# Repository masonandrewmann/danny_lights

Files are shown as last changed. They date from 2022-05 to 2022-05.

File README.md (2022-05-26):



# the cyberbar - wifi artnet/dmx + IR led lighting fixtures 
using ESP8266 for individually addressable LED bars controllable through both IR remote and wifi Artnet network

example

## User Guide!
Hello and welcome to the *magical* light fixtures that can be controlled via a handy 44 key infrared remote OR from a lighting console, computer, or mobile device via DMX lighting protocol. This is a walkthrough of how to use the lights. 

### IR remote mode

Put switch in IR position and use your 44 key remote! Here is what it does:
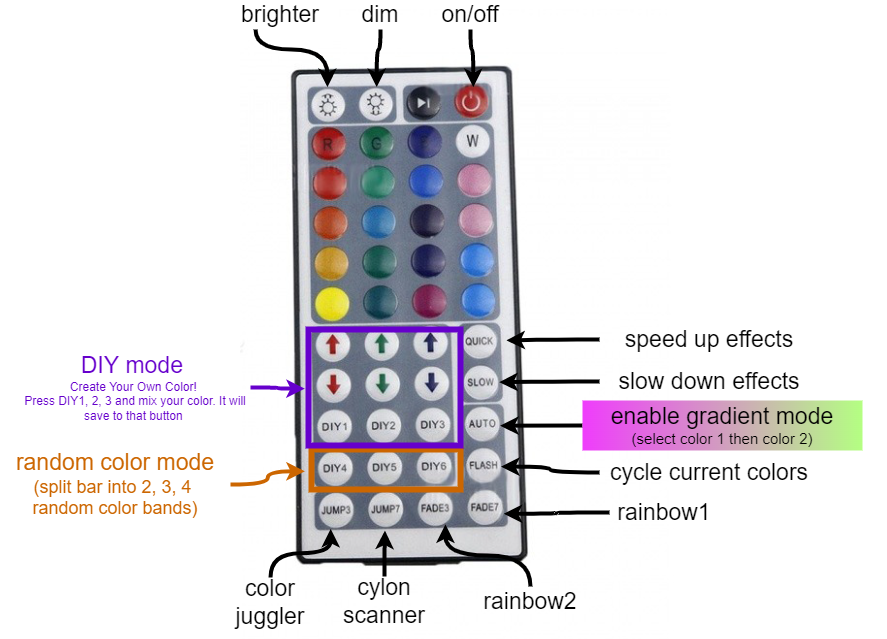
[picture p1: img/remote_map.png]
remote

### Wifi Artnet/DMX mode
#### WIFI setup 
  - put switch in DMX position
  - It will initially be in "Access Point" mode. Connect to the device as you would connect to a new wifi router. It will be called 'Cyberbar' initially in your wifi setup. 
    - username: CyberBar1 (or 2 or 3)
    - password: password
  - Once you are connected to it, you should be taken to IP address **192.168.4.1** in your browswer. The screen should look like this: 

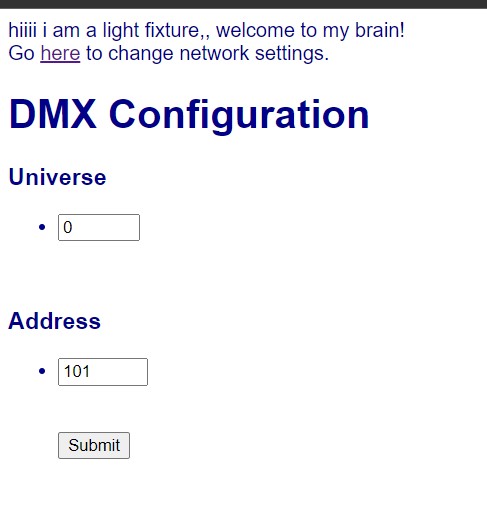
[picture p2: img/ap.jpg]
access
   
  - ArtNet typically starts at Universe 0! Check your console/lighting program for what universe you start at. 
  - Set the DMX address. 
  - If you want to connect multiple fixtures together, or use this in conjunction with something else, click the link to change the wifi settings. The page will look like this:
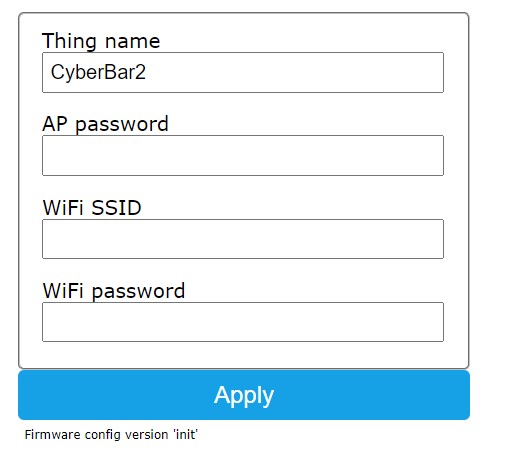
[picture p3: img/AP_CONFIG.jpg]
network
  
  - you can change the name of the fixture, and connect to another wifi network using its SSID and Password. This way you can connect many fixutres on the same network, or connect the fixture to the internet to control remotely.  
  - **reset button:** hold while turning on to reset the WIFI network to access point mode. 
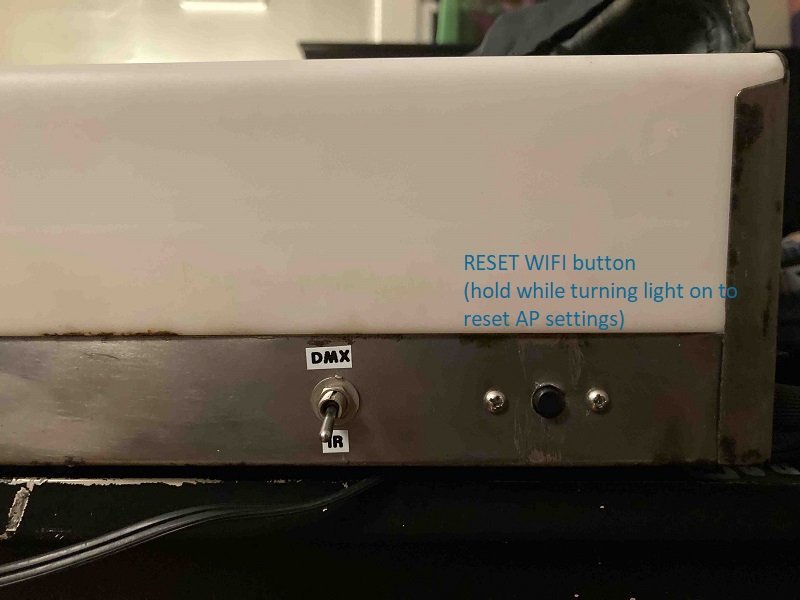
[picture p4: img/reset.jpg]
reset
 

#### DMX settings
  - set as 3 channel fixtures with 32 pixels in each fixture ([example setup shown here](https://htmlpreview.github.io/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))
    - color mode = RGB

behold the beauty!
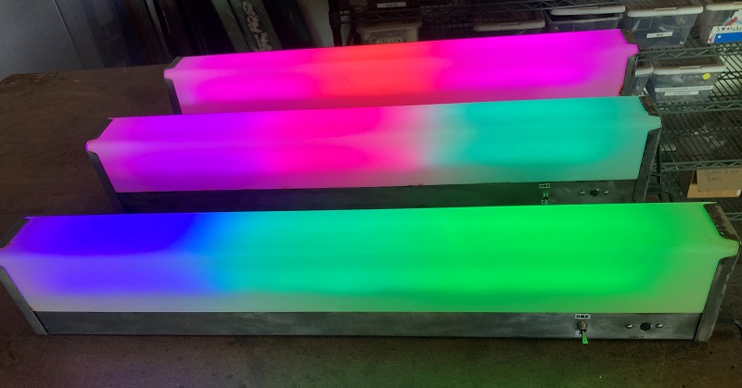
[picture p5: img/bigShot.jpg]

## installation guide for setting up your own:
I am assuming you are using the classic Arduino IDE!
 
IR code was modifed from [dmonty2's wonderful repo](https://github.com/dmonty2/ir_remote_leds)

make sure you install ESP8266 board add-ons for the IDE, [here](https://randomnerdtutorials.com/how-to-install-esp8266-board-arduino-ide/) is instructions on how to do that 

Only tested with ESP8266 using "NodMCU 1.0 (ESP-12E Module)" as the board. 

### required libraries: 
IOT and WIFI stuff: 
 - [IOTWebConf.h](https://github.com/prampec/IotWebConf) // NOTE: This library has been modified so that it stores in EEPROM starting at address 8 instead of 0, use the version included in this repository rather than the official release OR change the line "# define IOTWEBCONF_CONFIG_START 0" to "# define IOTWEBCONF_CONFIG_START 8" in IotWebConf.h in the official release. **The updated file is in library/IotWebConf.h. Move this into your Arduino library folder!**
- [ArtnetWifi.h ](https://github.com/natcl/Artnet) - not to be confused with other artnet wifi libraries,  this is the one to use

LED stuff: 
- [Adafruit_NeoPixel.h](https://github.com/adafruit/Adafruit_NeoPixel)
- [FastLED](https://github.com/FastLED/FastLED)
  
Infrared (IR) reciever stuff: 
- [IRRemoteESP8266](https://github.com/crankyoldgit/IRremoteESP8266)
-  [IRremote](https://github.com/NicoHood/IRLremote)  (outdated?)

Misc Libraries to include: 
- EEPROM.h , should be inheirited from the ESP8266 board library 

### hardware notes
Here are the interals: 
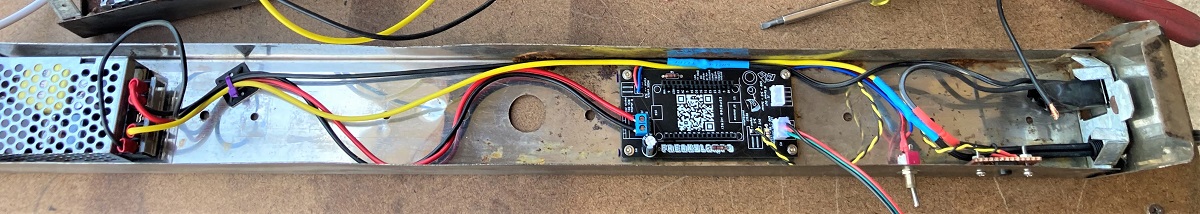
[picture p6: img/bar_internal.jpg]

Here is the schematic: 
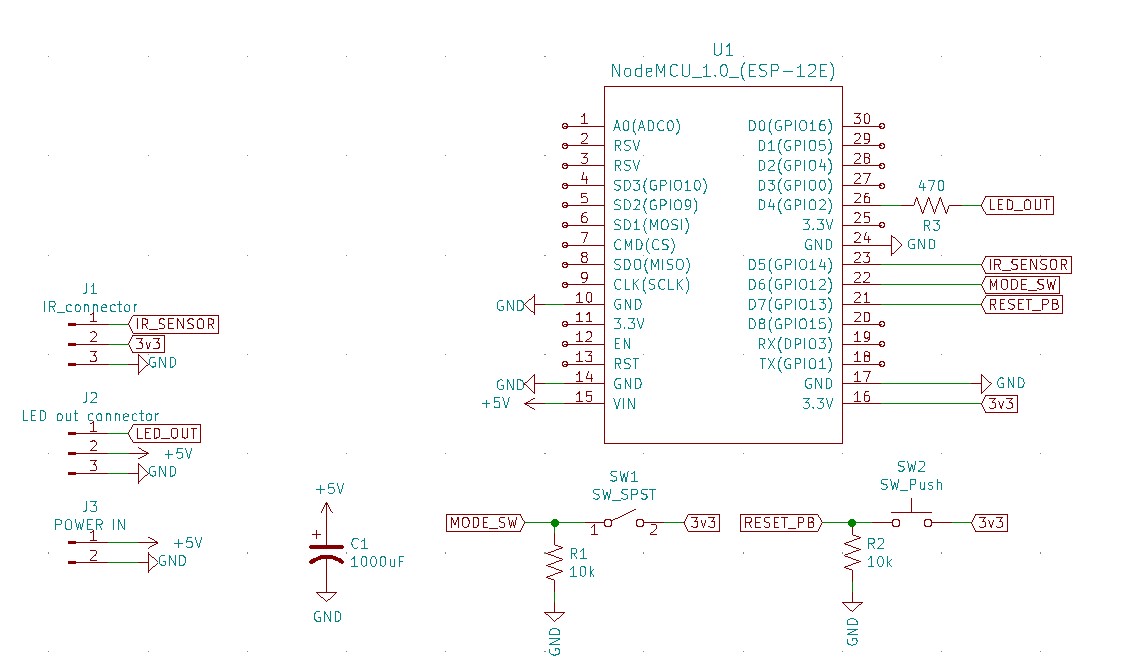
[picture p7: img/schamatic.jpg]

Included in the repo is a KiCad file for a PCB for the ESP8266:
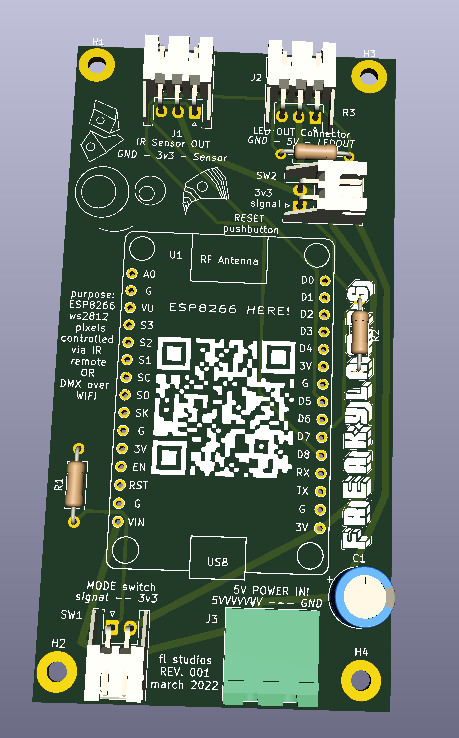
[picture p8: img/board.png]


## pinout for esp8266

LEDPIN          16 // D0    (built in indicator)

BUTTONPIN       13 // D7    (reset button)

MODEPIN         12 // D6    (dmx or IR)

ir recieiver =  14 // D5

led output     2 // D4      (addressable led output)

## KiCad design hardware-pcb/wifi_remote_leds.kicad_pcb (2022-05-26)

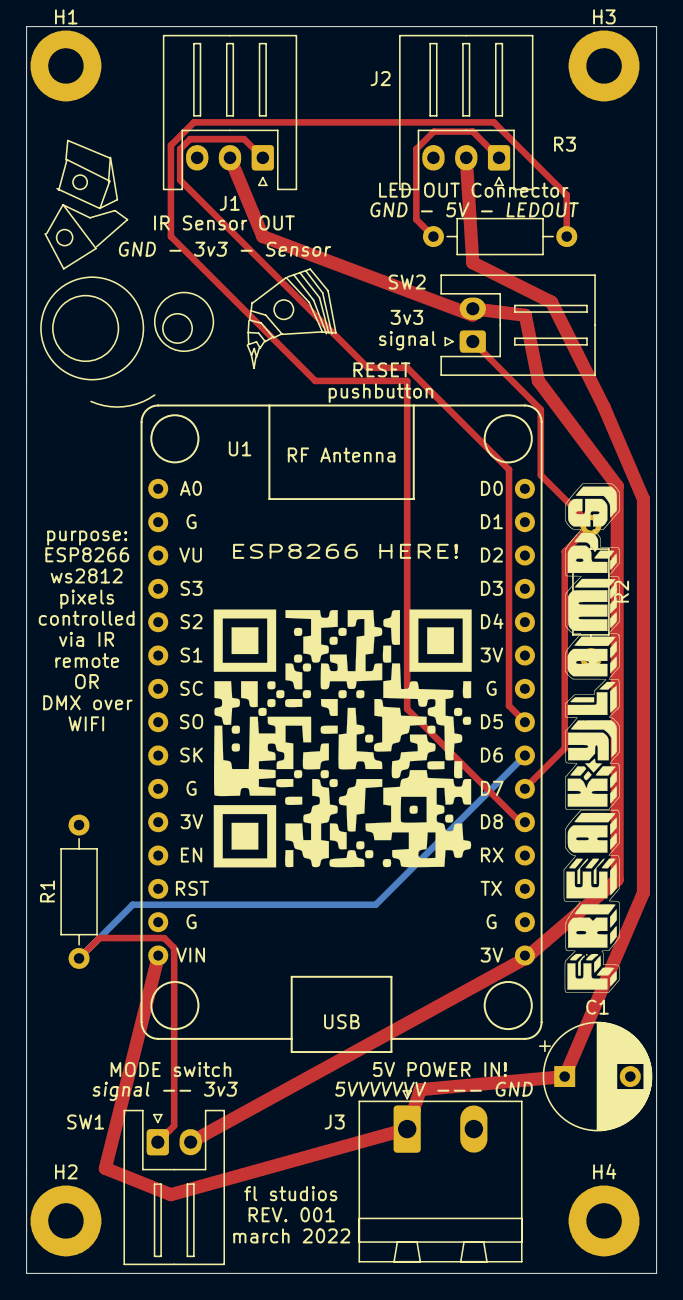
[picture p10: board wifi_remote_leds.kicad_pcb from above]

Board: 2 copper layers, 48.0 x 95.0 mm, 14 parts (0 on the bottom side), 8 nets.

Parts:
C1: 1000uF; CP_Radial_D8.0mm_P5.00mm
H1, H2, H3, H4: MountingHole; MountingHole_2.7mm_M2.5_Pad
J1: IR_connector; JST_XH_S3B-XH-A_1x03_P2.50mm_Horizontal
J2: LED out connector; JST_XH_S3B-XH-A_1x03_P2.50mm_Horizontal
J3: POWER IN; PhoenixContact_MSTBA_2,5_2-G-5,08_1x02_P5.08mm_Horizontal
R1, R2: 10k; R_Axial_DIN0207_L6.3mm_D2.5mm_P10.16mm_Horizontal
R3: 470; R_Axial_DIN0207_L6.3mm_D2.5mm_P10.16mm_Horizontal
SW1: SW_SPST; JST_XH_S2B-XH-A_1x02_P2.50mm_Horizontal
SW2: SW_Push; JST_XH_S2B-XH-A_1x02_P2.50mm_Horizontal
U1: NodeMCU_1.0_(ESP-12E); NodeMCU1.0(12-E)

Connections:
3v3: J1.2, SW1.2, SW2.2, U1.16
+5V: C1.1, J2.2, J3.1, U1.15
GND: C1.2, J1.3, J2.3, J3.2, R1.2, R2.2, U1.10, U1.14, U1.17, U1.24
IR_SENSOR: J1.1, U1.23
LED_OUT: J2.1, R3.1
MODE_SW: R1.1, SW1.1, U1.22
unnamed: R3.2, U1.20
RESET_PB: R2.1, SW2.1, U1.21

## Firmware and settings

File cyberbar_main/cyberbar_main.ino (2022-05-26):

/*
  FastLED + standard 44 Key Ir RGB Led remote + Teensy 3.2
 MMason Mann 3.2.2021
  Adapted from Dean Montgomery --- 44-key IR remote customization
  https://github.com/dmonty2/ir_remote_leds
*/

// south river wifi: RT-AC66U_B1_40_2G

//from wifi config code
#include <EEPROM.h>
#include <IotWebConf.h>
#include <ArtnetWifi.h> // https://github.com/natcl/Artnet  
#include <Adafruit_NeoPixel.h>
#define FASTLED_ESP8266_RAW_PIN_ORDER
#include <FastLED.h>
#include <IRremoteESP8266.h>
#include <IRrecv.h>
#include <IRutils.h>

#define IR_TOLERANCE 8
#define LEDPIN 16 //built in
#define BUTTONPIN 13 // D7 on esp8266 dev boad
#define MODEPIN 12 // D6 on esp8266 dev board

///EEPROM STRUCTURE
//0 -- effect number
//1 -- color for solid color
//4 -- color 1 for gradient
//7 -- color 2 for gradient
//10 --- number of bands for randomBands
//13 --- brightness
//16 DIY1 Color
//19 DIY2 Color
//22 DIY3 Color
//25 -- DMX Universe Number
//30 -- DMX Starting Address Number
//35 -- IOT Library Stuff

//EEPROM addresses
int addr_universeNum = 25;
int addr_dmxAdr = 30;

int universeNum;
int dmxAdr;

// -- Initial name of the Thing. Used e.g. as SSID of the own Access Point.
const char thingName[] = "CyberBar1";

// -- Initial password to connect to the Thing, when it creates an own Access Point.
const char wifiInitialApPassword[] = "password";

DNSServer dnsServer;
WebServer server(80);

IotWebConf iotWebConf(thingName, &dnsServer, &server, wifiInitialApPassword);

int status = WL_IDLE_STATUS;

// Artnet settings
ArtnetWifi artnet;

// An IR detector/demodulator is connected to GPIO pin 14(D5 on a NodeMCU
// board).
// Note: GPIO 16 won't work on the ESP8266 as it does not have interrupts.
const uint16_t kRecvPin = 14;

IRrecv irrecv(kRecvPin);

decode_results signals;

uint32_t IRCommand;
boolean haveWePickedColors;

//LED setup
#define DATA_PIN    2 // D4 on ESP8266
#define LED_TYPE    WS2812B
#define COLOR_ORDER GRB
#define NUM_LEDS    32
#define BRIGHTNESS          200   // GLOBAL brightness scale

CRGB leds[NUM_LEDS];
CRGB ledColors[NUM_LEDS];
CHSV color;
CHSV color1;
CHSV color2;
boolean powerOn = true;
enum Rgb { RED, GREEN, BLUE };

//other variables setups

int colorIndex;
#define MIN_intrvl 10  // fastest the led libraries can update without loosing access to PIR remote sensing.
long    intrvl = 40;
unsigned long currentMillis = millis(); // define here so it does not redefine in the loop.
unsigned long previousMillis = 0;
uint8_t effect = 0;
uint8_t h = 0; //hue
uint8_t s = 255; //saturation
uint8_t v = 255; //value
uint8_t brightnessFactor = 20 ; // how many steps to from full bright to black out
uint8_t brightnessInterval = BRIGHTNESS / brightnessFactor ; /// BRIGHTNESS (overall brighntess// max brigtness) divided by btightness factor creates the interval you step by
uint8_t brightness = BRIGHTNESS; // this is new brightness ( BRIGHTNESS - the brightness factor)
uint8_t bands;
boolean initialized = false;

#define SOLIDCOLOR 1
#define GRADIENT 2
#define RANDOMBANDS 3
#define FADE7 4
#define FADE3 5
#define SINELON 6
#define JUGGLE 7
#define BARBERPOLE 8
#define BRIGHT 9
#define DIM 10
#define BARBERPOLE1 11
#define BARBERPOLE2 12
#define EASTEREGGPOLE 13

uint8_t randNumber1;
uint8_t randNumber2;
uint8_t randNumber3;

struct buttonNames {
  uint32_t bright;   uint32_t dim;        uint32_t ppause;     uint32_t power;
  uint32_t red1;     uint32_t green1;     uint32_t blue1;      uint32_t white1;
  uint32_t red2;     uint32_t green2;     uint32_t blue2;      uint32_t white2;
  uint32_t red3;     uint32_t green3;     uint32_t blue3;      uint32_t white3;
  uint32_t red4;     uint32_t green4;     uint32_t blue4;      uint32_t white4;
  uint32_t red5;     uint32_t green5;     uint32_t blue5;      uint32_t white5;
  uint32_t red_up;   uint32_t green_up;   uint32_t blue_up;    uint32_t quick;
  uint32_t red_down; uint32_t green_down; uint32_t blue_down;  uint32_t slow;
  uint32_t diy1;     uint32_t diy2;       uint32_t diy3;       uint32_t autom;
  uint32_t diy4;     uint32_t diy5;       uint32_t diy6;       uint32_t flash;
  uint32_t jump3;    uint32_t jump7;      uint32_t fade3;      uint32_t fade7;
};

//// These are the codes for my remote
const buttonNames remote =  {
  0xFF3AC5,   0xFFBA45,   0xFF827D,   0xFF02FD,
  0xFF1AE5,   0xFF9A65,   0xFFA25D,   0xFF22DD,
  0xFF2AD5,   0xFFAA55,   0xFF926D,   0xFF12ED,
  0xFF0AF5,   0xFF8A75,   0xFFB24D,   0xFF32CD,
  0xFF38C7,   0xFFB847,   0xFF7887,   0xFFF807,
  0xFF18E7,   0xFF9867,   0xFF58A7,   0xFFD827,
  0xFF28D7,   0xFFA857,   0xFF6897,   0xFFE817,
  0xFF08F7,   0xFF8877,   0xFF48B7,   0xFFC837,
  0xFF30CF,   0xFFB04F,   0xFF708F,   0xFFF00F,
  0xFF10EF,   0xFF906F,   0xFF50AF,   0xFFD02F,
  0xFF20DF,   0xFFA05F,   0xFF609F,   0xFFE01F,
};

uint32_t commandsArray[] =  {
  0xFF3AC5,   0xFFBA45,   0xFF827D,   0xFF02FD,
  0xFF1AE5,   0xFF9A65,   0xFFA25D,   0xFF22DD,
  0xFF2AD5,   0xFFAA55,   0xFF926D,   0xFF12ED,
  0xFF0AF5,   0xFF8A75,   0xFFB24D,   0xFF32CD,
  0xFF38C7,   0xFFB847,   0xFF7887,   0xFFF807,
  0xFF18E7,   0xFF9867,   0xFF58A7,   0xFFD827,
  0xFF28D7,   0xFFA857,   0xFF6897,   0xFFE817,
  0xFF08F7,   0xFF8877,   0xFF48B7,   0xFFC837,
  0xFF30CF,   0xFFB04F,   0xFF708F,   0xFFF00F,
  0xFF10EF,   0xFF906F,   0xFF50AF,   0xFFD02F,
  0xFF20DF,   0xFFA05F,   0xFF609F,   0xFFE01F,
};

CHSV r1 (0, 255, 255);
CHSV g1 (96, 255, 255);
CHSV b1 (160, 255, 255);
CHSV w1 (4, 10, 255);
CHSV r2 (16, 255, 255);
CHSV g2 (112, 255, 255);
CHSV b2 (176, 255, 255);
CHSV w2  (52, 200, 255);
CHSV r3 (32, 255, 255);
CHSV g3 (120, 255, 255);
CHSV b3 (192, 255, 255);
CHSV w3 (45, 200, 255);
CHSV r4 (48, 255, 255);
CHSV g4 (128, 255, 255);
CHSV b4 (208, 255, 255);
CHSV w4 (96, 70, 255);
CHSV r5 (60, 255, 255);
CHSV g5 (136, 255, 255);
CHSV b5 (224, 255, 255);
CHSV w5 (64, 60, 255);

// CHSV Color Array

CHSV CHSV_array[] = { r1, g1, b1, w1,
                      r2, g2, b2, w2,
                      r3, g3, b3, w3,
                      r4, g4, b4, w4,
                      r5, g5, b5, w5
                    };

                    // storing diy in eeprom

uint8_t r = 0; //red
uint8_t g = 0; //green
uint8_t b = 0; //blue
#define SLIDE_VALUE 110
#define SLIDE_RGB 111
uint8_t slide = SLIDE_VALUE;
uint8_t last_white = 0;
CHSV water[NUM_LEDS];

struct DIY {
  uint8_t r; uint8_t g; uint8_t b;
};
//Track start points in eeprom index
static uint16_t eeprom_addr[] = {16, 19, 22};

struct DIY_BUTTON {
  uint8_t button;
  bool dirty;
};
DIY_BUTTON lastdiy = { 0, false };
/*
struct DIYSTORE {
  DIY diy1; DIY diy2; DIY diy3; // stored at 0,  3,  6
  DIY diy4; DIY diy5; DIY diy6; // stored at 9, 12, 15
};
 size of EEPROM: 1024 bytes
 size of 44 key remote: 176 bytes
 size of DIY: 3 bytes
 size of DIYSTORE: 18 bytes
 */

void setup() {
  //------------------------SETUP FOR ARTNET MODE------------------------
  Serial.begin ( 115200 );
     while (!Serial)  // Wait for the serial connection to be establised.
    delay(50);
  Serial.println("Setup begin");
  EEPROM.begin(512);
  pinMode(MODEPIN, INPUT);
  
  artnet.begin();
  artnet.setArtDmxCallback(onDmxFrame);
  
  //read eeprom to set global DMX configuration variables
  universeNum = readIntFromEEPROM(addr_universeNum);
  dmxAdr = readIntFromEEPROM(addr_dmxAdr);
  Serial.println("Universe Num from EEPROM: ");
  Serial.println(universeNum);
  Serial.println("Starting Address from EEPROM:");
  Serial.println(dmxAdr);
  Serial.println("iot eeprom start ");
  Serial.println(IOTWEBCONF_CONFIG_START);

  // ACCESS POINT CONFIG
    // -- Initializing the configuration.
    pinMode(BUTTONPIN, INPUT);
  if (digitalRead(BUTTONPIN) == 0){
    Serial.println("Skipping Access Point Setup Mode");
    iotWebConf.skipApStartup();
  } else {
    Serial.println("Entering Access Point Setup Mode");
  }
  iotWebConf.init();
  iotWebConf.setStatusPin(LEDPIN);
  pinMode(LEDPIN, OUTPUT);

  // -- Set up required URL handlers on the web server.
  server.on("/", handleRoot);
  server.on ( "/submit", handleSubmit );
  server.on("/config", []{ iotWebConf.handleConfig(); });
  server.onNotFound([](){ iotWebConf.handleNotFound(); });

  Serial.println("Ready.");

  //------------------------setup for IR remote mode------------------------
  irrecv.enableIRIn();  // Start the receiver
  Serial.println();
  Serial.print("IRrecvDemo is now running and waiting for IR message on Pin ");
  Serial.println(kRecvPin);
  
//  pinMode(13, OUTPUT);
//  digitalWrite(13, HIGH);   // turn the LED on (HIGH is the voltage level)

  randomSeed(analogRead(0));
  // In case the interrupt driver crashes on setup, give a clue
  // to the user what's going on.
  Serial.println("Enabling IRin");
  irrecv.enableIRIn(); // Start the receiver
  Serial.println("Enabled IRin");
  FastLED.addLeds<LED_TYPE, DATA_PIN, COLOR_ORDER>(leds, NUM_LEDS).setCorrection(TypicalLEDStrip);
  // set master BRIGHTNESS control
  FastLED.setBrightness(BRIGHTNESS);
  FastLED.clear();  // clear all pixel data
  FastLED.show();

  startFromEEPROM();
//  EEPROM.get(0, effect); // get that effect number
//  Serial.print("EEPROM loading-- ");
//  Serial.println(effect);
//  
//  if (effect == SOLIDCOLOR) {
//    EEPROM.get(1, color);
//    solidColor(color);
//  }
//  if (effect == GRADIENT) {
//    EEPROM.get(4, color1);
//    EEPROM.get(7, color2);
//    fill_gradient(leds, 0, color1, NUM_LEDS, color2, SHORTEST_HUES);
//    FastLED.show();
//  }
//  if (effect == RANDOMBANDS) {
//    EEPROM.get(10, bands);
//    randomBands(bands);
//  }
}

void loop() {
  int tempMode = digitalRead(MODEPIN); //read switch to move between Art-Net mode and IR mode
  if (tempMode == 1){
  // Art-Net Mode
    iotWebConf.doLoop();  
    artnet.read();
    if (initialized){
      initialized = false;
    }
  } 
  
  else {
    if (!initialized){
      startFromEEPROM();
    }
  currentMillis = millis();
  if (!irrecv.decode(&signals)) {
    if (currentMillis - previousMillis > intrvl) {
      previousMillis = currentMillis;
      update_effect();
      FastLED.show();
    }
  }
  if (irrecv.decode(&signals)) {
    // print() & println() can't handle printing long longs. (uint64_t)
    mainButton();
    serialPrintUint64(signals.value, HEX);
    Serial.println("");
    irrecv.resume();  // Receive the next value
  }
  delay(100);
  }
}

String getPage(){
  String s = "<!DOCTYPE html><html lang=\"en\"><head><meta name=\"viewport\" content=\"width=device-width, initial-scale=1, user-scalable=no\"/>";
  s += "<title>IotWebConf 01 Minimal</title></head><body>hiiii i am a light fixture,, welcome to my brain!<br>";
  s += "Go <a href='config'>here</a> to change network settings.";
  s += "<title>Light Bar</title>";
  s += "<style> body { background-color: #fffff; font-family: Arial, Helvetica, Sans-Serif; Color: #000088; }</style>";
  s += "</head><body><h1>DMX Configuration</h1>";
  s += "<h3>Universe</h3>";
  s += "<form action='/submit' method='POST'>";
  s += "<ul><li><input type='number' name='Uni' id='Uni' value='" + String(universeNum) + "' min='0' max='24'>";
  s += "</li></ul>";
  s += "<br>";
  s += "<h3>Address</h3>";
  s += "<form action='submit' method='POST'>";
  s += "<ul><li><input type='number' name='Adr' id = 'Adr' value ='" + String(dmxAdr) + "' min='0' max='512'>";
  s += "<br><br><br>";
  s += "<input type = 'submit' value='Submit'></li></ul>";
  s += "</body></html>\n";
  return s;
}

void writeIntIntoEEPROM(int address, int number)
{ 
  EEPROM.write(address, (number >> 24) & 0xFF);
  EEPROM.write(address + 1, (number >> 16) & 0xFF);
  EEPROM.write(address + 2, (number >> 8) & 0xFF);
  EEPROM.write(address + 3, number & 0xFF);
  EEPROM.commit();  
}

int readIntFromEEPROM(int address)
{
  return ((int)EEPROM.read(address) << 24) +
         ((int)EEPROM.read(address + 1) << 16) +
         ((int)EEPROM.read(address + 2) << 8) +
         (int)EEPROM.read(address + 3);
}
 
void handleSubmit(){

  Serial.println ("handleSubmit");
  //fetch DMX configuration
    String universeNumStr = server.arg(0);
    String dmxAdrStr = server.arg(1);
  //convert DMX configuration to ints
    universeNum = universeNumStr.toInt();
    dmxAdr = dmxAdrStr.toInt();
  //annnnd write it into EEPROM
    writeIntIntoEEPROM(addr_universeNum, universeNum);
    writeIntIntoEEPROM(addr_dmxAdr, dmxAdr);
    if (EEPROM.commit()) {
      Serial.println("EEPROM successfully committed");
    } else {
      Serial.println("ERROR! EEPROM commit failed");
    }
   
  String
  message = "URI: ";
  message += server.uri();
  message += "\nMethod: ";
  message += (server.method() == HTTP_GET)?"GET":"POST";
  message += "\nArguments: ";
  message += server.args();
  message += "\n";
  for (uint8_t i=0; i<server.args(); i++){
    message += " " + server.argName(i) + ": " + server.arg(i) + "\n";
  }
  Serial.println(message);
  Serial.println("Universe Number:");
  Serial.println(universeNum);
  Serial.println("DMX Address:");
  Serial.println(dmxAdr);
  server.send ( 200, "text/html", getPage() );
}

/**
 * Handle web requests to "/" path.
 */
void handleRoot()
{
  // -- Let IotWebConf test and handle captive portal requests.
  if (iotWebConf.handleCaptivePortal())
  {
    // -- Captive portal request were already served.
    return;
  }
  String s = getPage();
  server.send(200, "text/html", s);
}

void onDmxFrame(uint16_t universe, uint16_t length_, uint8_t sequence, uint8_t* data)
{
  int universeFromEEPROM = readIntFromEEPROM(addr_universeNum);
  int startAddressFromEEPROM = readIntFromEEPROM(addr_dmxAdr);
//  Serial.println("-----FRAME RECIEVED-------");
//  Serial.println(universe);
//  Serial.println(universeFromEEPROM);
//  Serial.println(startAddressFromEEPROM);
//  Serial.println(length_);

    if (universe == universeFromEEPROM){
//      Serial.println("correct Universe");
    for (int i = 0; i < NUM_LEDS; i++)
    {
//      Serial.println(i);
        leds[i].setRGB(
          data[startAddressFromEEPROM + i * 3 - 1],
          data[startAddressFromEEPROM + i * 3],
          data[startAddressFromEEPROM + i * 3 + 1]
          );
    }
  }
//  Serial.println("Done printing frame");   
    FastLED.show();
}

void mainButton() {
//  IRCommand = getButton();
  IRCommand = signals.value;
  if (IRCommand == remote.power) {
//    FastLED.clear();  // clear all pixel data
//    FastLED.show();
//    effect = 0; //ot to reset the effect counter so we dont go into the  effects loop
//    Serial.println("power");
//    startFromEEPROM();
    if (powerOn){
      FastLED.setBrightness(brightness);
    } else {
      FastLED.setBrightness(0);
    }
    powerOn = !powerOn;
  }

  //definitions for just solid colors
  if ( IRCommand == remote.red1 || IRCommand == remote.green1 || IRCommand == remote.blue1 || IRCommand == remote.white1 ||
       IRCommand == remote.red2 || IRCommand == remote.green2 || IRCommand == remote.blue2 || IRCommand == remote.white2 ||
       IRCommand == remote.red3 || IRCommand == remote.green3 || IRCommand == remote.blue3 || IRCommand == remote.white3 ||
       IRCommand == remote.red4 || IRCommand == remote.green4 || IRCommand == remote.blue4 || IRCommand == remote.white4 ||
       IRCommand == remote.red5 || IRCommand == remote.green5 || IRCommand == remote.blue5 || IRCommand == remote.white5 ) {
    for (int i = 4; i < 24; i++) { //the first 4 buttons are not color buttons, so we dont wanna scan through those in the array
//      Serial.println("buttonNum: " + i);
      if (IRCommand == commandsArray[i]) {
        colorIndex = i - 4;
        Serial.print("THE color index is: ");
        Serial.println(i);
      }
    }
    CHSV color =  CHSV_array[colorIndex];
    effect = SOLIDCOLOR;
    solidColor(color);
    //nscale8_video(brightness); // dim to max brightness
    FastLED.show();

    EEPROM.put(0, effect); // Eeprom address 0 is effect/mode
    EEPROM.put(1, color); // eeprom address 1,2,3 are color1
    EEPROM.commit();  
      Serial.println("solid_colors");
  }

  if (IRCommand == remote.autom) {
    FastLED.clear();  // clear all pixel data
    FastLED.show();
    staticGradient();
    IRCommand = 0x00000000;
    haveWePickedColors = false;
    effect = GRADIENT; // got to reset the effect counter so we dont go into the  effects loop
    EEPROM.put(0, effect);
    EEPROM.commit();  
      Serial.println("autom");
  }

  if (IRCommand == remote.jump3) {
    // stage = 1;
    intrvl = 65;
    h = 0; s = 255; v = 0;
    effect = JUGGLE;
    EEPROM.put(0, effect);
    EEPROM.commit();  
      Serial.println("jump3");
  }
  if (IRCommand == remote.jump7) {
    Serial.println("jump 7");
    //  stage = 1;
    intrvl = MIN_intrvl;
    h = 0; s = 255; v = 0;
    effect = SINELON;
    EEPROM.put(0, effect);
    EEPROM.commit();  
  }
  if (IRCommand == remote.fade3) {
    Serial.println("fade 3");
    //stage = 1;
    intrvl = 65;
    h = 0; s = 255; v = 0;
    effect = FADE3;
    EEPROM.put(0, effect);
    EEPROM.commit();  
  }
  if (IRCommand == remote.fade7) {
    intrvl = 65;
    effect = FADE7;
    h = 0; s = 255; v = 255;
    EEPROM.put(0, effect);
    EEPROM.commit();  
      Serial.println("fade 7");
  }
  if (IRCommand == remote.bright) {
    brightness = brightness + brightnessInterval;
    if (brightness > BRIGHTNESS) {
      brightness = BRIGHTNESS;
    }
    FastLED.setBrightness(brightness);
    FastLED.show();
    Serial.print("brightness pressed. brightness = ");
    Serial.println(brightness);
    EEPROM.put(13, brightness);
    EEPROM.commit();  
  }

  if (IRCommand == remote.dim) {
    brightness = brightness - brightnessInterval;
    if (brightness > BRIGHTNESS) {
      brightness = 0;
    }
    FastLED.setBrightness(brightness);
    FastLED.show();
    Serial.print("dimmer pressed. brightness = ");
    Serial.println(brightness);
    EEPROM.put(13, brightness);
    EEPROM.commit();  
  }
  if (IRCommand == remote.slow) {
    if (intrvl >= 100) {
      intrvl += 100;
    } else {
      intrvl += 15;
    }
    Serial.print("slow pressed. interval = ");
    Serial.println(intrvl);
  }
  if (IRCommand == remote.quick) {
    if ( intrvl >= 101 ) {
      intrvl -= 100;
    } else if ( intrvl >= MIN_intrvl + 10 && intrvl <= 100 ) {
      intrvl -= 10;
    } else {
      intrvl = MIN_intrvl;
    }
    Serial.print("quick pressed. interval = ");
    Serial.println(intrvl);
  }
  if (IRCommand == remote.diy1) {
    Serial.println("diy1");
    updateDiy(0);
  }
  if (IRCommand == remote.diy2) {
    Serial.println("diy2");
    updateDiy(1);
  }
  if (IRCommand == remote.diy3) {
    Serial.println("diy3");
    updateDiy(2);
  }
  if (IRCommand == remote.diy4) {
    effect = RANDOMBANDS;
    bands = 2;
    randomBands(bands);
    EEPROM.put(0, effect);
    EEPROM.put(10, bands);
    EEPROM.commit();  
    Serial.println("diy4");
  }
  if (IRCommand == remote.diy5) {
    effect = RANDOMBANDS;
    bands = 3;
    randomBands(bands);
    EEPROM.put(0, effect);
    EEPROM.put(10, bands);
    EEPROM.commit();  
    Serial.println("diy5");
  }
  if (IRCommand == remote.diy6) {
    effect = RANDOMBANDS;
    bands = 4;
    randomBands(bands);
    EEPROM.put(0, effect);
    EEPROM.put(10, bands);
    EEPROM.commit();  
    Serial.println("diy6");
  }
  if (IRCommand == remote.red_up) {
    colorUpDown(RED, 10); 
  }
  if (IRCommand == remote.green_up) {
    colorUpDown(GREEN, 10); 
  }
  if (IRCommand == remote.blue_up) {
    colorUpDown(BLUE, 10); 
  }
  if (IRCommand == remote.red_down) {
    colorUpDown(RED, -10); 
  }
  if (IRCommand == remote.green_down) {
    colorUpDown(GREEN, -10); 
  }
  if (IRCommand == remote.blue_down) {
    colorUpDown(BLUE, -10); 
  }
  if (IRCommand == remote.flash) {
    intrvl = 0;
    if (effect == BARBERPOLE) {
      effect = BARBERPOLE1;
    } else if (effect == BARBERPOLE1) {
      effect = BARBERPOLE2;
    } else if (effect == BARBERPOLE2) {
      effect = EASTEREGGPOLE;
    } else {
      effect = BARBERPOLE;
    }
    Serial.println("flash");
  }
//  if (IRCommand != remote.red_up && IRCommand != remote.green_up && IRCommand != remote.blue_up &&
//      IRCommand != remote.red_down && IRCommand != remote.green_down && IRCommand != remote.blue_down && lastdiy.dirty){
//        lastdiy.dirty = false;
//      }

//check if we need to exit diy loop
  boolean realButton = false; //check if the ir code corresponds to a button
    for (int i = 0; i < 44; i++) { //the first 4 buttons are not color buttons, so we dont wanna scan through those in the array
//      Serial.println("buttonNum: " + i);
      if (IRCommand == commandsArray[i] && IRCommand != remote.red_up && IRCommand != remote.green_up && IRCommand != remote.blue_up &&
        IRCommand != remote.red_down && IRCommand != remote.green_down && IRCommand != remote.blue_down && lastdiy.dirty) {
        Serial.println("exiting diy mode");
        lastdiy.dirty = false;
        lastdiy.button = 0;
      }
    }
}

//////////////////////////////////////////////////////////////////////////////////////////////////////////////////////////////////////////////////////////////
//////////////////////END OF GET BUTTON FUNC ///////////////////////////////////
////////////////////////////////////////////////////////////////////////////////

void solidColor(CHSV color) {
  for (int i = 0; i < NUM_LEDS; i++) {
    leds[i] = color;
  }
  FastLED.show();
}
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

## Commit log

2021-01-07 added mode switch button on GPIO15 (D8 on dev board). Wired with a 10k pulldown
2021-01-07 button pin switched to GPIO13 (D7). Integrated access point and DMX input code.
2021-01-07 fixed EEPROM overwriting issue and cleaned some print statements
    [webserver_input.ino]
2021-01-07 Add files via upload
    artnet over wifi sketch from Fly On A Wall frames. Included is a watchdog function that puts the thing to sleep if its not connected to a network. we can take that out. we should make it so that it h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
2021-02-09 began integrating artnet and ir, fixed EEPROM overlap
    [danny-lights-main.ino]
2021-02-09 fixed EEPROM for real and integrated the two program modes
    [danny-lights-main.ino]
2021-03-03 fixed a bug where bad IR values would exit diy mode
    [danny-lights-main.ino]
2021-03-03 eeprom fixed with commit messages
    [danny-lights-main.ino]
2022-05-26 readme and more
    [wifi_remote_leds-B_Cu.gbr, wifi_remote_leds-B_Mask.gbr, wifi_remote_leds-B_Paste.gbr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]
